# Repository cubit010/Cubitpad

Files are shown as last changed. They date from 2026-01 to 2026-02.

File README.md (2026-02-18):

# Cubitpad
The Cubitpad is a macropad that is designed to maximize functionality in the smallest footprint. It utilizes all pins to their maximum extent on the Seeeduino XIAO RP2040 for the most features, which includes: NKRO 3x3 macro, rotary encoder with push function, and a 0.91" OLED monochrome screen, the keypad also being backlit with neopixels for some flair

### Usage
To use, one should flash their xiao rp2040 with the correct circuitpython .uf2 file, upload the code file, as well as libraries and linked images, save, and you're good to go!
you can customize what each key does, lighting color, text displays, etc all within the code.py file

### Creation
This was initially created as my own current keyboard lacks a rotary encoder, and I wanted one for volume and other controls, which then spiraled into this project

# Image
S__15409169

# Cad


# PCB


# Schematic


# Case by itself



Friction fitted (with clearance designed for 3d printing)
(I can print this myself, but some filament could be nice)

# Firmware
- KMK based,
- Screen used for identifying layers, icon display, and signature display
- Neopixel used for backlight
- Custom rotary encoder decoding software from one analog pin
- Custom Key object designed for the rotary encoder multi function button
- Advanced use of macros and hotkeys for daily use

# BOM
| Qty | Item | Notes |
|-----|---|---|
| 1 | SEEEDUINO XIAO RP2040 | Microcontroller board |
| 9 | MX-style switches | |
| 9 | 1N4148 through-hole diodes | For switch matrix |
| 1 | SSD1306 128x32 OLED 0.91" | I2C display |
| 9 | Blank DSA keycaps | |
| 1 | 1x4 2.54mm female header | For raising display height |
| 1 | EC11 rotary encoder | |
| 1 | 10kΩ metal film resistor | Part of voltage divider |
| 1 | 47kΩ metal film resistor | Voltage divider |
| 1 | 100kΩ metal film resistor | Voltage divider |
| 9 | Kailh MX hot-swap sockets | For hot-swappable switches |

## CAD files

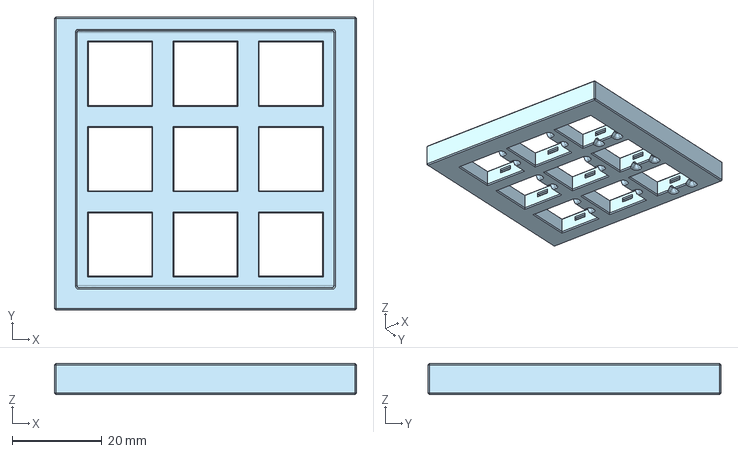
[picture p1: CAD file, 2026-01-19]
CAD/keyboard plate v1.step
67.4 x 65.4 x 7.00 mm

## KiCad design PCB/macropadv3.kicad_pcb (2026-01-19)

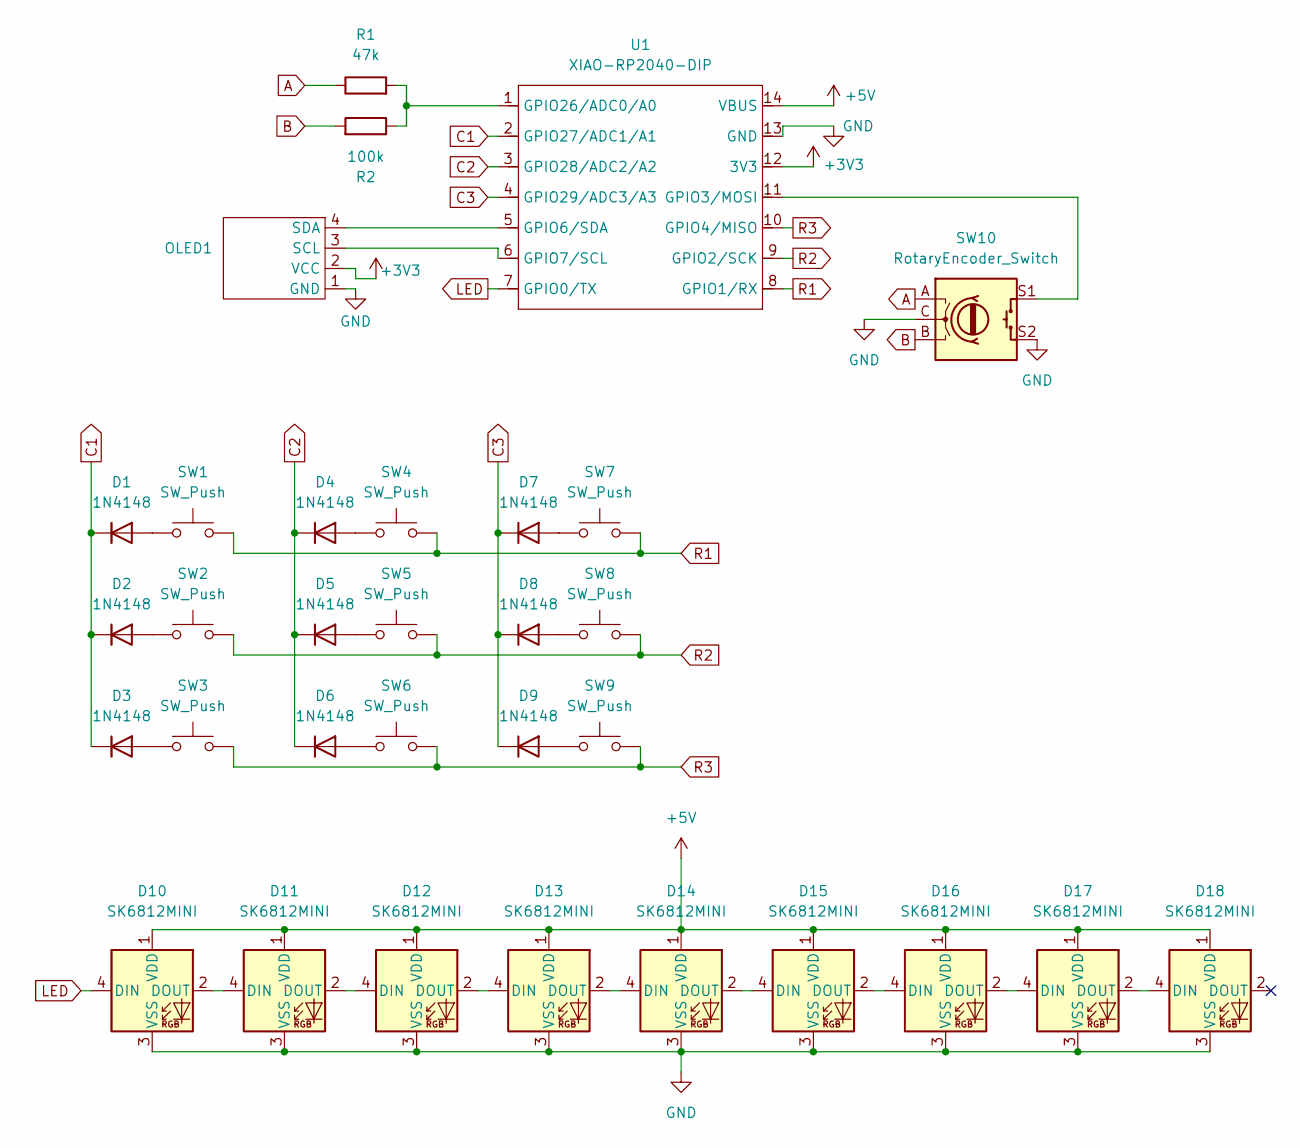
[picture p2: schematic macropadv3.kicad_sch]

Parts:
D1, D2, D3, D4, D5, D6, D7, D8, D9: 1N4148; D_DO-35_SOD27_P7.62mm_Horizontal
D10, D11, D12, D13, D14, D15, D16, D17, D18: SK6812MINI; MX_SK6812MINI-E_REV
OLED1: SSD1306-0.91-OLED-4pin-128x32
R1: 47k; R_Axial_DIN0207_L6.3mm_D2.5mm_P10.16mm_Horizontal
R2: 100k; R_Axial_DIN0207_L6.3mm_D2.5mm_P10.16mm_Horizontal
SW1, SW2, SW3, SW4, SW5, SW6, SW7, SW8, SW9: SW_Push; MX-Hotswap-1U
SW10: RotaryEncoder_Switch; RotaryEncoder_Alps_EC11E-Switch_Vertical_H20mm
U1: XIAO-RP2040-DIP

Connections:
+3V3: OLED1.2 (VCC), U1.12 (3V3)
+5V: D10.1 (VDD), D11.1 (VDD), D12.1 (VDD), D13.1 (VDD), D14.1 (VDD), D15.1 (VDD), D16.1 (VDD), D17.1 (VDD), D18.1 (VDD), U1.14 (VBUS)
A: R1.1, SW10.A
B: R2.2, SW10.B
C1: D1.1 (K), D2.1 (K), D3.1 (K), U1.2 (GPIO27/ADC1/A1)
C2: D4.1 (K), D5.1 (K), D6.1 (K), U1.3 (GPIO28/ADC2/A2)
C3: D7.1 (K), D8.1 (K), D9.1 (K), U1.4 (GPIO29/ADC3/A3)
GND: D10.3 (VSS), D11.3 (VSS), D12.3 (VSS), D13.3 (VSS), D14.3 (VSS), D15.3 (VSS), D16.3 (VSS), D17.3 (VSS), D18.3 (VSS), OLED1.1 (GND), SW10.C, SW10.S2, U1.13 (GND)
LED: D10.4 (DIN), U1.7 (GPIO0/TX)
unnamed: D1.2 (A), SW1.2
unnamed: D2.2 (A), SW2.2
unnamed: D3.2 (A), SW3.2
unnamed: D4.2 (A), SW4.2
unnamed: D5.2 (A), SW5.2
unnamed: D6.2 (A), SW6.2
unnamed: D7.2 (A), SW7.2
unnamed: D8.2 (A), SW8.2
unnamed: D9.2 (A), SW9.2
unnamed: D10.2 (DOUT), D11.4 (DIN)
unnamed: D11.2 (DOUT), D12.4 (DIN)
unnamed: D12.2 (DOUT), D13.4 (DIN)
unnamed: D13.2 (DOUT), D14.4 (DIN)
unnamed: D14.2 (DOUT), D15.4 (DIN)
unnamed: D15.2 (DOUT), D16.4 (DIN)
unnamed: D16.2 (DOUT), D17.4 (DIN)
unnamed: D17.2 (DOUT), D18.4 (DIN)
unnamed: OLED1.3 (SCL), U1.6 (GPIO7/SCL)
unnamed: OLED1.4 (SDA), U1.5 (GPIO6/SDA)
unnamed: SW10.S1, U1.11 (GPIO3/MOSI)
unnamed: R1.2, R2.1, U1.1 (GPIO26/ADC0/A0)
R1: SW1.1, SW4.1, SW7.1, U1.8 (GPIO1/RX)
R2: SW2.1, SW5.1, SW8.1, U1.9 (GPIO2/SCK)
R3: SW3.1, SW6.1, SW9.1, U1.10 (GPIO4/MISO)

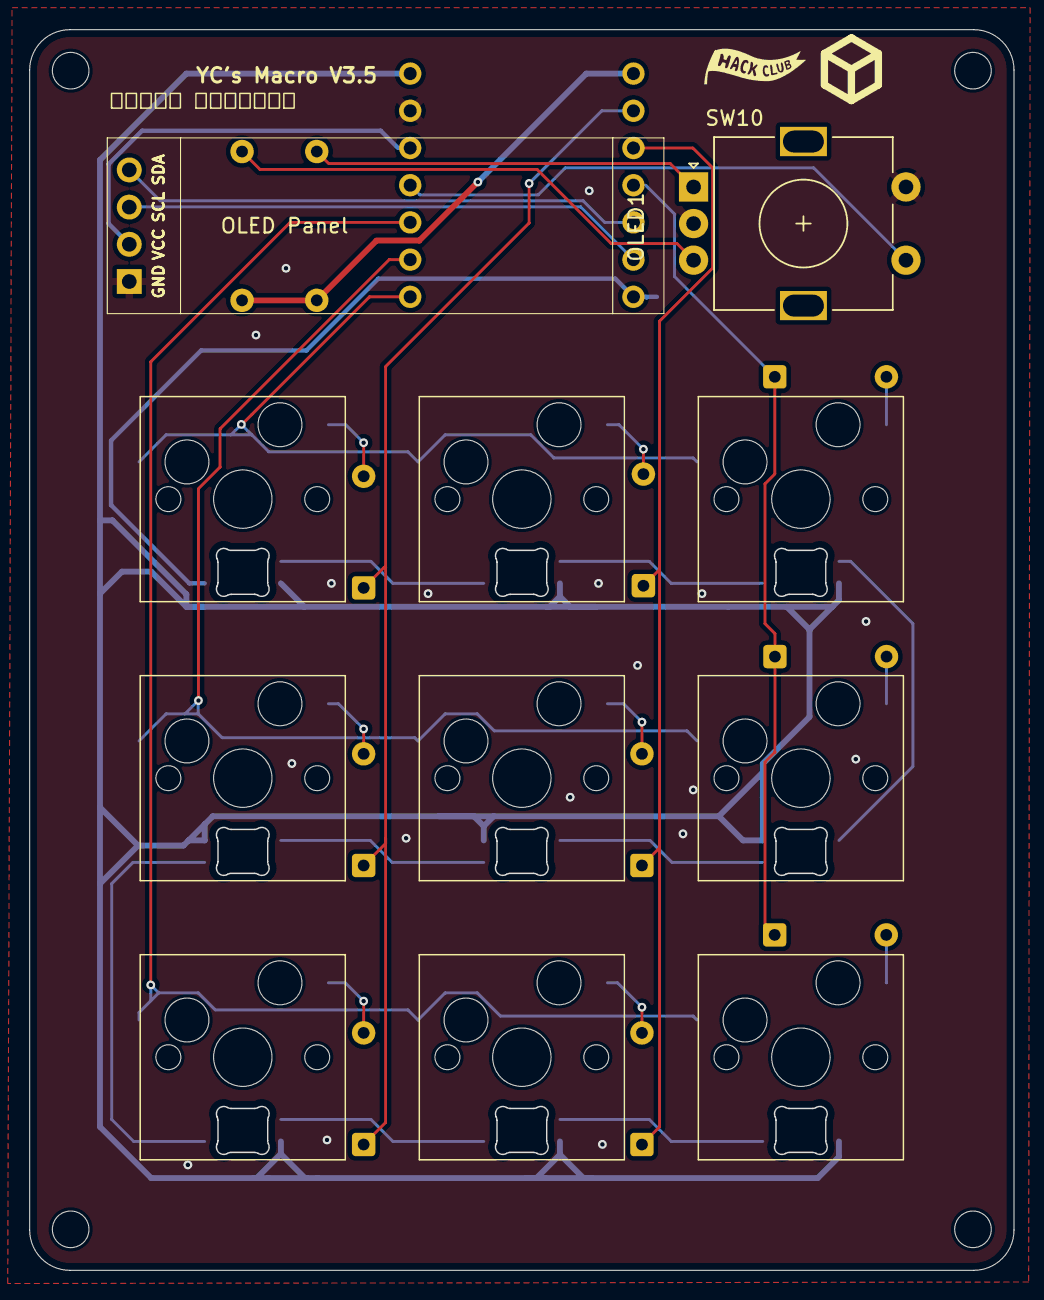
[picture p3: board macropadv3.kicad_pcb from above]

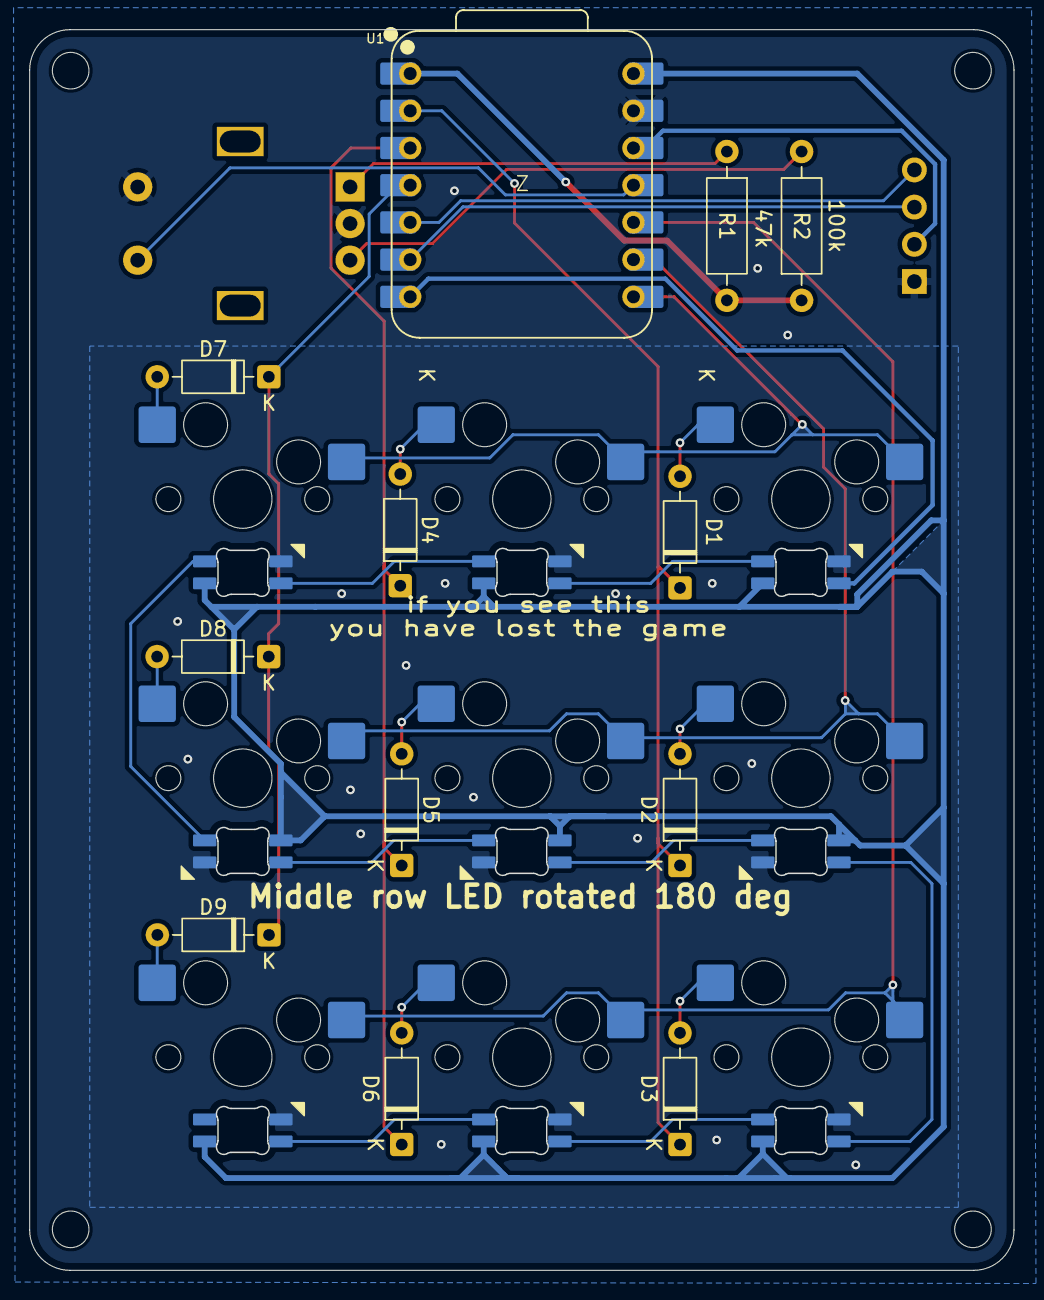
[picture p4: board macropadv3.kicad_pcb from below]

Board: 2 copper layers, 67.2 x 84.7 mm, 32 parts (21 on the bottom side), 33 nets.

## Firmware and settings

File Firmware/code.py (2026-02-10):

import board
from kmk.kmk_keyboard import KMKKeyboard
from kmk.keys import KC
from kmk.scanners import DiodeOrientation
from kmk.extensions.RGB import RGB
from kmk.extensions.rgb import AnimationModes
from kmk.modules.layers import Layers

from kmk.scanners.keypad import MatrixScanner
from kmk.scanners.keypad import KeysScanner
from kmk.modules import Module
import analogio
from kmk.extensions.media_keys import MediaKeys


class AnalogResistorEncoder(Module):
    def __init__(self, pin, thresholds, cw_key, ccw_key):
        self.pin = pin
        self.thresholds = thresholds
        self.cw_key = cw_key
        self.ccw_key = ccw_key

        self.ain = None
        self.last_state = None

    def during_bootup(self, keyboard):
        self.ain = analogio.AnalogIn(self.pin)
        return

    def before_matrix_scan(self, keyboard):
        val = self.ain.value
        state = self._state_from_adc(val)

        # Debug on state change
        if self.last_state is None:
            print("Initial state:", state, "ADC:", val)

        elif state != self.last_state:
            print("STATE CHANGE:", self.last_state, "→", state, "ADC:", val)

            # Only detect transitions FROM state 3
            if self.last_state == 3:
                if state == 2:
                    keyboard.tap_key(self.ccw_key)
                elif state == 1:
                    keyboard.tap_key(self.cw_key)

        self.last_state = state
        return keyboard

    #
    # Helper
    #

    def _state_from_adc(self, val):
        for i, t in enumerate(self.thresholds):
            if val < t:
                return i
        return len(self.thresholds)

    #
    # Required no-op hooks
    #

    def after_matrix_scan(self, keyboard):
        return keyboard

    def before_hid_send(self, keyboard):
        return

    def after_hid_send(self, keyboard):
        return

    def on_powersave_enable(self, keyboard):
        return

    def on_powersave_disable(self, keyboard):
        return

class CubitPad(KMKKeyboard):
    def __init__(self):
        super().__init__()

        # create and register the scanner
        self.matrix = [
            MatrixScanner(
                column_pins=(board.D1, board.D2, board.D3),
                row_pins=(board.D7, board.D8, board.D9),
                columns_to_anodes=DiodeOrientation.ROW2COL
            ),
            KeysScanner(
                #rotary encoder single key scanner
                pins=[board.D10],
                value_when_pressed=False,
            ),
        ]
    
keyboard = CubitPad()
keyboard.extensions.append(MediaKeys())

encoder = AnalogResistorEncoder(
    pin=board.A0,
    thresholds=[1270, 10000, 40000],
    cw_key=KC.VOLU,
    ccw_key=KC.VOLD,
)

keyboard.modules.append(encoder)

LEDON = True

class LayerRGB(RGB):
    def on_layer_change(self, layer):
        if LEDON:
            if layer == 0:
                self.set_hsv_fill(79, self.sat_default, self.val_default)   # 
            elif layer == 1:
                self.set_hsv_fill(170, self.sat_default, self.val_default) # blue
            elif layer == 2:
                self.set_hsv_fill(20, self.sat_default, self.val_default) # 
            elif layer == 3:
                self.set_hsv_fill(180, self.sat_default, self.val_default) # 
            elif layer == 4:
                self.set_hsv_fill(225, self.sat_default, self.val_default) # 
            elif layer == 5:
                self.set_hsv_fill(0, 0, self.val_default) # 
        else:
                self.set_hsv_fill(0, 0, 0) # off

        if layer == 6:
            self.set_hsv_fill(0, 0, 0)
            self.set_hsv(0, self.sat_default, 100 if LEDON else 40 , 8) # 
            self.set_hsv(0, self.sat_default, 30 if LEDON else 10, 3)
        self.show()

    def on_layer_change_flash(self):
        if LEDON:
            self.set_hsv_fill(0, 255, 15)
        else:
            self.set_hsv_fill(0, 255, 10)
        self.show()
# import neopixel
# --- RGB LEDS ---
rgb = LayerRGB(
    pixel_pin=board.D6,
    num_pixels=9,
    hue_default=79,
    sat_default=255,
    val_default=67,
    # pixels = neopixel.NeoPixel(
    #             board.D6,
    #             9,
    #             pixel_order=(1,0,2),
    #         )
)

keyboard.extensions.append(rgb)

class RGBLayers(Layers):
    def __init__(self):
        super().__init__()
        self.lay = 0
    def activate_layer(self, keyboard, layer, idx=None):
        super().activate_layer(keyboard, layer, idx)
        if(layer != 6):
            rgb.on_layer_change_flash()
            time.sleep(0.15)
            self.lay= layer
        rgb.on_layer_change(layer)

    def deactivate_layer(self, keyboard, layer):
        super().deactivate_layer(keyboard, layer)
        rgb.on_layer_change_flash()
        rgb.on_layer_change(keyboard.active_layers[0])


keyboard.modules.append(RGBLayers())




# --- LAYERS ---
layers = RGBLayers()
keyboard.modules.append(layers)
from kmk.modules.macros import Delay, Press, Release, Tap
from kmk.modules.macros import Macros
macros = Macros()
keyboard.modules.append(macros)
from kmk.keys import KC

MAC1 = KC.MACRO("chargoggagoggmanchauggagoggchaubunagungamaugg")

MAC2 = KC.MACRO(
    " 000000000011111111112222222222333333333344444444445555555555666666666677777777778888888888999999999900000000 "
    # # "/",
    # Delay(30),
    # "crazy? I was crazy once\n",
    # # "/",
    # Delay(30),
    # "they locked me in a room, a rubber room\n",
    # # "/",
    # Delay(30),
    # "a rubber room with rats\n",
    # # "/",
    # Delay(30),
    # "and rats drive me crazy\n",
)


MUTE = KC.MACRO(
    Press(KC.RALT),
    Press(KC.RSHIFT),
    Tap(KC.M),
    Release(KC.RALT),
    Release(KC.RSHIFT)
)

DEAF = KC.MACRO(
    Press(KC.RALT),
    Press(KC.RSHIFT),
    Tap(KC.D),
    Release(KC.RALT),
    Release(KC.RSHIFT)
)

VOLDN = KC.MACRO(
    Press(KC.RALT),
    Tap(KC.PIPE),
    Release(KC.RALT)
)

VOLUP = KC.MACRO(
    Press(KC.RCTRL),
    Press(KC.RALT),
    Tap(KC.PIPE),
    Release(KC.RALT),
    Release(KC.RCTRL)
)

PIF3 = KC.MACRO(
    Press(KC.LSHIFT),
    Tap(KC.F3),
    Release(KC.LSHIFT)
)

DEC = KC.MACRO(
    Press(KC.LSHIFT),
    Press(KC.F3),
    Tap(KC.F),
    Release(KC.F3),
    Release(KC.LSHIFT)
)

INC = KC.MACRO(
    Press(KC.F3),
    Tap(KC.F),
    Release(KC.F3)
)

COP = KC.MACRO(
    Press(KC.LSHIFT),
    Press(KC.LGUI),
    Tap(KC.F23),
    Release(KC.LGUI),
    Release(KC.LSHIFT)
)

TERM = KC.MACRO(
    
    Tap(KC.LGUI),
    "term",
    Tap(KC.ENT)
)

SPEC = KC.MACRO(
    "leave me alone\n"
    "i'm filling out my special olympics application\n"    
)


from kmk.extensions.display import Display, TextEntry, ImageEntry
from kmk.modules.holdtap import HoldTap
holdtap = HoldTap()
# optional: set a custom tap timeout in ms
# holdtap.tap_time = 300
keyboard.modules.append(holdtap)


from kmk.keys import Key

rotaryMute = True

img1 = "sound16.bmp"
img2 = "play16.bmp"
# textdisp = TextEntry(text= txt1, x=101, y=0, layer=None)
icondisp = ImageEntry(image="sound16.bmp", x=112)
class RotKey(Key):
   
    def __init__ (self, key1, key2):
        self.key = key1
        self.altkey = key2

    def on_press(self, keyboard, coord_int = None):
        if rotaryMute:
            keyboard.add_key(self.key)
        else:
            keyboard.add_key(self.altkey)

    def on_release(self, keyboard, coord_int = None):
        if rotaryMute:
            keyboard.remove_key(self.key)
        else:
            keyboard.remove_key(self.altkey)

class RotSwap(Key):
    def on_press(self, keyboard, coord_int = None):
        # print("swapped")
        
        global rotaryMute
        rotaryMute = not rotaryMute
        global icondisp
        icondisp.setImage(img1 if rotaryMute else img2)
        display.render(layers.lay)
        print(rotaryMute)

class LedTog(Key):
    def on_press(self, keyboard, coord_int = None):
        global LEDON
        LEDON = not LEDON
        
encTap = RotKey(KC.MUTE, KC.MPLY)
encHold = RotSwap()
rgbtog = LedTog()

ENCP = KC.HT(encTap, encHold, prefer_hold=True, tap_interrupted=False, tap_time=300)

MODE = KC.HT(KC.ENTER, KC.MO(6), prefer_hold= True, tap_time=180, )
MODE1 = KC.HT(KC.N9, KC.MO(6), prefer_hold= True, tap_time=180, )
# --- MEME KEYMAP ---
keyboard.keymap = [
    # Default
    [
        MAC1, MAC2, KC.SPACE,
        VOLDN, KC.MPLY, VOLUP,
        MUTE, DEAF, MODE,
        ENCP
    ],
    # speedrun
    [
        DEC, INC, PIF3,
        VOLDN, KC.MPLY, VOLUP,
        MUTE, DEAF, MODE,
        ENCP
    ],
    # EDITING
    [
        COP, TERM, PIF3,
        VOLDN, KC.MPLY, VOLUP,
        MUTE, DEAF, MODE,
        ENCP
    ],
    # custom 1
    [
        KC.A, KC.S, SPEC,
        KC.NO, KC.K, KC.L,
        KC.SPC, KC.SPC, MODE,
        ENCP
    ],
    # custom 2
    [
        KC.RGB_MODE_RAINBOW, KC.RGB_ANI, KC.RGB_AND,
        KC.RGB_MODE_PLAIN, KC.NO, KC.NO,
        KC.NO, KC.NO, MODE,
        ENCP
    ],
    # numpad
    [
        KC.N1, KC.N2, KC.N3,
        KC.N4, KC.N5, KC.N6,
        KC.N7, KC.N8, MODE1,
        ENCP
    ],
    # redirect
    [
        KC.TO(0), KC.TO(1), KC.TO(2),
        KC.TO(3), KC.TO(4), KC.TO(5),
        KC.NO, rgbtog, KC.TRNS,
        KC.RELOAD
    ]

]


import busio, time



# For SSD1306
from kmk.extensions.display.ssd1306 import SSD1306

# Replace SCL and SDA according to your hardware configuration.
i2c_bus = busio.I2C(board.SCL, board.SDA)

driver = SSD1306(
    # Mandatory:
    i2c=i2c_bus,
)

display = Display(
    # Mandatory:
    display=driver,
    # Optional:
    width=128, # screen size
    height=32, # screen size
    flip = False, # flips your display content
    flip_left = False, # flips your display content on left side split
    flip_right = False, # flips your display content on right side split
    brightness=0.4, # initial screen brightness level
    brightness_step=0.1, # used for brightness increase/decrease keycodes
    dim_time=20, # time in seconds to reduce screen brightness
    dim_target=0.01, # set level for brightness decrease
    off_time=600, # time in seconds to turn off screen
    powersave_dim_time=10, # time in seconds to reduce screen brightness
    powersave_dim_target=0.001, # set level for brightness decrease
    # powersave_off_time=30, # time in seconds to turn off screen
)

display.entries = [
    # ImageEntry(image="cornerDebug.bmp", x=0, y=0),

    # ImageEntry(image="InvRoll.bmp", x=5, y=0),'

    TextEntry(text="Cubitpad v3.5", x=0, y=0),
    icondisp,
    TextEntry(text="Default", x=0, y=12, layer=0), 
    TextEntry(text="Speedrun", x=0, y=12, layer=1),
    TextEntry(text="Editing", x=0, y=12, layer=2),
    TextEntry(text="Osu Geo", x=0, y=12, layer=3),
    TextEntry(text="Custom 2", x=0, y=12, layer=4),
    TextEntry(text="Numpad", x=0, y=12, layer=5),
    TextEntry(text="Mode Swap", x=0, y=12, layer=6),
    # TextEntry(text="Hey there!", x=0, y=24),
]
keyboard.extensions.append(display)


if __name__ == "__main__":
    
    keyboard.go()

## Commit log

2025-11-30 Update README with CAD, PCB, and Schematic images
    Added images for CAD, PCB, and Schematic.
2025-11-30 Update README with case images and BOM
    Added images and BOM details for the project.
2025-11-30 Enhance README with images and updated information
    Added images for CAD, PCB, Schematic, and Case sections. Updated firmware and BOM information.
2025-11-30 Clarify friction fitted section in README
    Removed unnecessary comment about filament from the friction fitted section.
2025-12-01 Add rotary encoder to components list
2025-12-01 Remove SK6812-MINI-E LED from README
    Removed SK6812-MINI-E LED from the parts list.
2026-01-19 update pcb files to v3, added file for plate
    [macropadv2.kicad_pcb, macropadv2.kicad_sch]
2026-01-19 update pcb to v3.5, as well as adding plate cad file
    [keyboard plate v1.step, macropadv3.kicad_pcb, macropadv3.kicad_sch]
2026-01-19 updating images to v3.5 of pcb design
2026-01-19 update bom to materials needed for v3.5
2026-02-10 Enhance firmware section in README
    Expanded firmware section with additional details on screen usage, Neopixel backlight, rotary encoder functionality, and macro capabilities.
2026-02-10 Fix typo and add new resistor to parts list
2026-02-18 Revise BOM format and add item notes
    Updated the Bill of Materials (BOM) table format for clarity and added notes for each item.
2026-02-18 Add BOM.csv with component list for project
    [BOM.csv]
